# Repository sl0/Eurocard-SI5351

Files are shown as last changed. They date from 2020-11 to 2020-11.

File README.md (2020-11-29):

# Eurocard-SI5351

This repo will contain an arduino sketch and KiCad files for a pcb.
The pcb shall output stable 25 and 40 MHz sine, derived from a 10MHz
OCXO or external GPSDO 10MHz

## Licenses

The arduino sketch is licensed under the terms of GNU General Public
License.

    https://www.gnu.org/licenses/#GPL

Files in the kicad directory are 'Open Source' under the terms of the
definition for Open Source Hardware Association.

    http://www.oshwa.org/definition/

## Arduino Sketch

A first sketch I got from Wolfram DF7KB, after he made some experiments
to reduce phase noise. The genious trick was to rely on integer
operations only in the synthesizer. It was derived from the examples 
found in 
[etherkit libraries][].

## KiCad files

The schema of the board is easy:

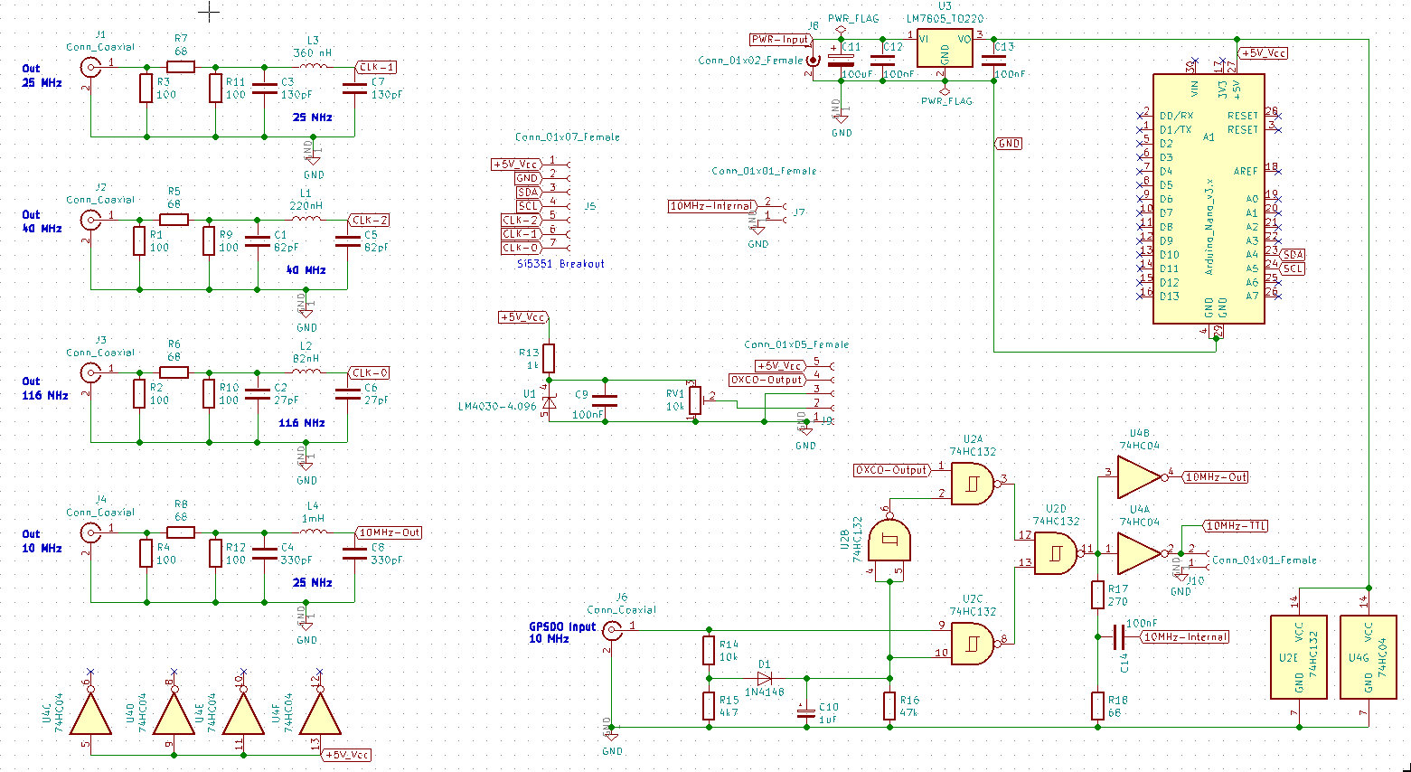
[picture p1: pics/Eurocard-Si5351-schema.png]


The routing of the pcb was done by hand:

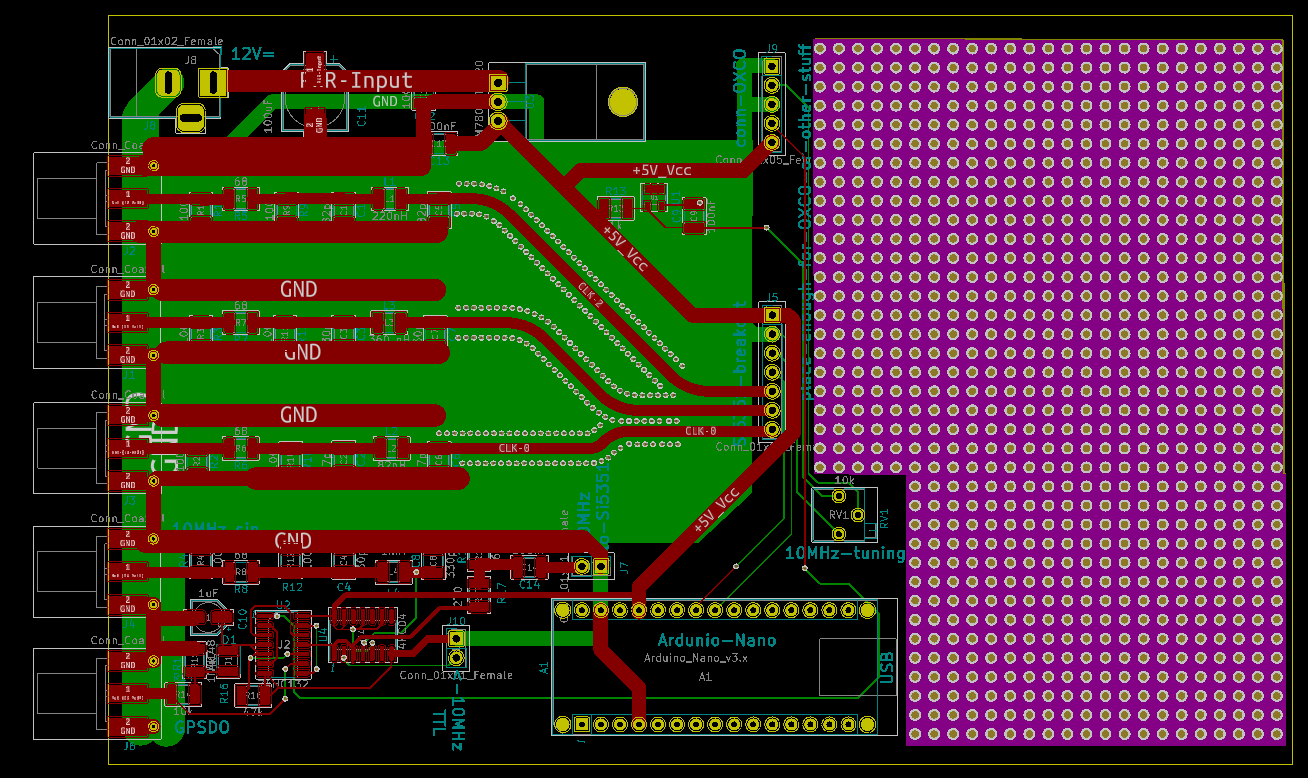
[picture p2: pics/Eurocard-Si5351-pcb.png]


    Have fun!

    sl0

[etherkit libraries]: https://github.com/etherkit/Si5351Arduino

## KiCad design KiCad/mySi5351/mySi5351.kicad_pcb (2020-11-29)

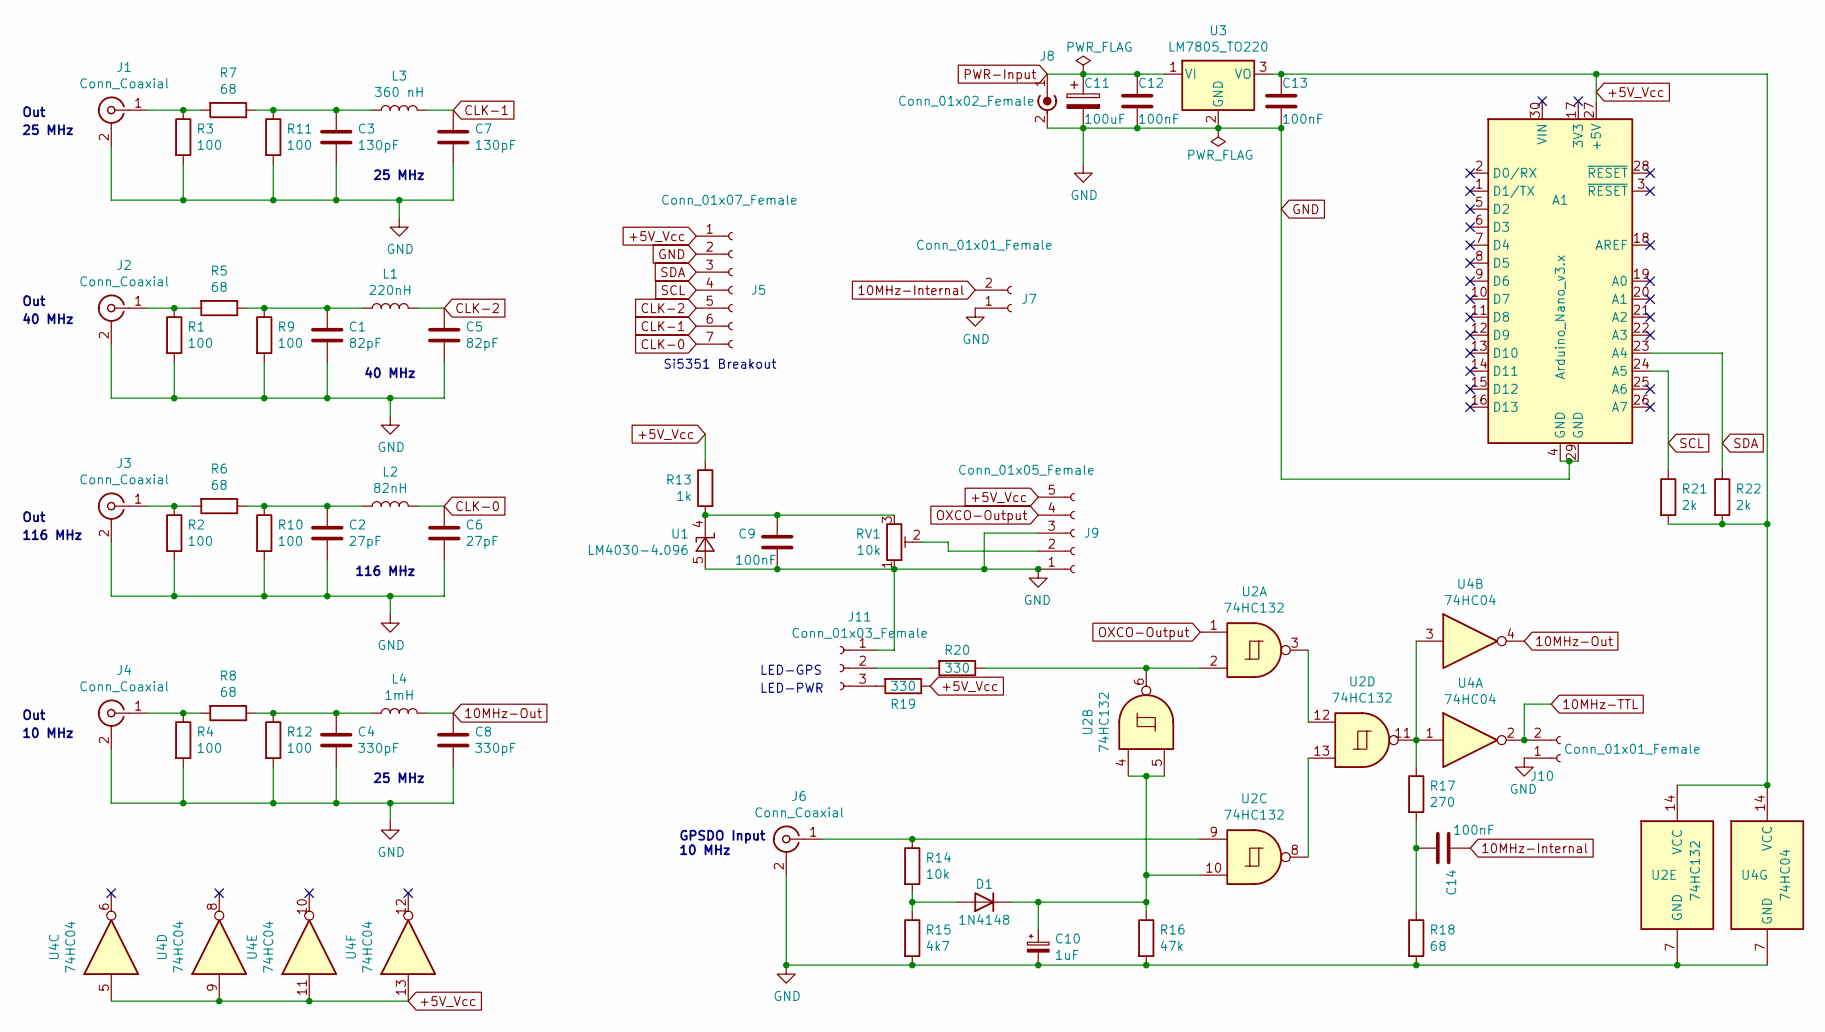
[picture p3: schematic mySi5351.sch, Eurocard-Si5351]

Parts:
A1: Arduino_Nano_v3.x; Arduino_Nano_WithMountingHoles
C1, C5: 82pF; C_1210_3225Metric_Pad1.33x2.70mm_HandSolder
C2, C6: 27pF; C_1210_3225Metric_Pad1.33x2.70mm_HandSolder
C3, C7: 130pF; C_1210_3225Metric_Pad1.33x2.70mm_HandSolder
C4, C8: 330pF; C_1210_3225Metric_Pad1.33x2.70mm_HandSolder
C9, C12, C13, C14: 100nF; C_1210_3225Metric_Pad1.33x2.70mm_HandSolder
C10: 1uF; CP_Elec_4x5.3
C11: 100uF; CP_Elec_8x10.5
D1: 1N4148; D_1210_3225Metric
J1, J2, J3, J4, J6: Conn_Coaxial; SMA_Molex_73251-1153_EdgeMount_Horizontal
J5: Conn_01x07_Female; PinHeader_1x07_P2.54mm_Vertical
J7, J10: Conn_01x01_Female; PinHeader_1x02_P2.54mm_Vertical
J8: Conn_01x02_Female; BarrelJack_Horizontal
J9: Conn_01x05_Female; PinHeader_1x05_P2.54mm_Vertical
J11: Conn_01x03_Female; PinHeader_1x03_P2.54mm_Vertical
L1: 220nH; L_1210_3225Metric_Pad1.42x2.65mm_HandSolder
L2: 82nH; L_1210_3225Metric_Pad1.42x2.65mm_HandSolder
L3: 360 nH; L_1210_3225Metric_Pad1.42x2.65mm_HandSolder
L4: 1mH; L_1210_3225Metric_Pad1.42x2.65mm_HandSolder
R1, R2, R3, R4, R9, R10, R11, R12: 100; R_1210_3225Metric_Pad1.30x2.65mm_HandSolder
R5, R6, R7, R8, R18: 68; R_1210_3225Metric_Pad1.30x2.65mm_HandSolder
R13: 1k; R_1210_3225Metric_Pad1.30x2.65mm_HandSolder
R14: 10k; R_1210_3225Metric_Pad1.30x2.65mm_HandSolder
R15: 4k7; R_1210_3225Metric_Pad1.30x2.65mm_HandSolder
R16: 47k; R_1210_3225Metric_Pad1.30x2.65mm_HandSolder
R17: 270; R_1210_3225Metric_Pad1.30x2.65mm_HandSolder
R19, R20: 330; R_1210_3225Metric_Pad1.30x2.65mm_HandSolder
R21, R22: 2k; R_1210_3225Metric_Pad1.30x2.65mm_HandSolder
RV1: 10k; Potentiometer_Bourns_3266P_Horizontal
U1: LM4030-4.096; SOT-23-5
U2: 74HC132; SO-14_3.9x8.65mm_P1.27mm
U3: LM7805_TO220; TO-220-3_Horizontal_TabDown
U4: 74HC04; SO-14_3.9x8.65mm_P1.27mm

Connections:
10MHz-Internal: C14.1, J7.2
10MHz-Out: C8.1, L4.2, U4.4
10MHz-TTL: J10.2, U4.2
+5V_Vcc: A1.27 (+5V), C13.1, J5.1, J9.5, R13.1, R19.1, R21.2, R22.2, U2.14 (VCC), U3.3 (VO), U4.5, U4.9, U4.11, U4.13, U4.14 (VCC)
CLK-0: C6.1, J5.7, L2.2
CLK-1: C7.1, J5.6, L3.2
CLK-2: C5.1, J5.5, L1.2
GND: A1.4 (GND), A1.29 (GND), C1.2, C2.2, C3.2, C4.2, C5.2, C6.2, C7.2, C8.2, C9.2, C10.2, C11.2, C12.2, C13.2, J1.2 (Ext), J2.2 (Ext), J3.2 (Ext), J4.2 (Ext), J5.2, J6.2 (Ext), J7.1, J8.2 (Ext), J9.1, J9.3, J10.1, J11.1, R1.2, R2.2, R3.2, R4.2, R9.2, R10.2, R11.2, R12.2, R15.2, R16.2, R18.2, RV1.1, U1.5 (A), U2.7 (GND), U3.2 (GND), U4.7 (GND)
unnamed: C1.1, L1.1, R5.1, R9.1
unnamed: C2.1, L2.1, R6.1, R10.1
unnamed: C3.1, L3.1, R7.1, R11.1
unnamed: C4.1, L4.1, R8.1, R12.1
unnamed: C9.1, R13.2, RV1.3, U1.4 (K)
unnamed: C10.1, D1.1 (K), R16.1, U2.4, U2.5, U2.10
unnamed: C14.2, R17.2, R18.1
unnamed: D1.2 (A), R14.2, R15.1
unnamed: J1.1 (In), R3.1, R7.2
unnamed: J2.1 (In), R1.1, R5.2
unnamed: J3.1 (In), R2.1, R6.2
unnamed: J4.1 (In), R4.1, R8.2
unnamed: J6.1 (In), R14.1, U2.9
unnamed: J9.2, RV1.2
unnamed: J11.2, R20.2
unnamed: J11.3, R19.2
unnamed: R17.1, U2.11, U4.1, U4.3
unnamed: R20.1, U2.2, U2.6
unnamed: U2.3, U2.12
unnamed: U2.8, U2.13
OXCO-Output: J9.4, U2.1
PWR-Input: C11.1, C12.1, J8.1 (In), U3.1 (VI)
SCL: A1.24 (A5), J5.4, R21.1
SDA: A1.23 (A4), J5.3, R22.1

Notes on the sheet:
Si5351 Breakout
GPSDO Input 10 MHz
25 MHz
40 MHz
116 MHz
10 MHz
Out
LED-GPS
LED-PWR

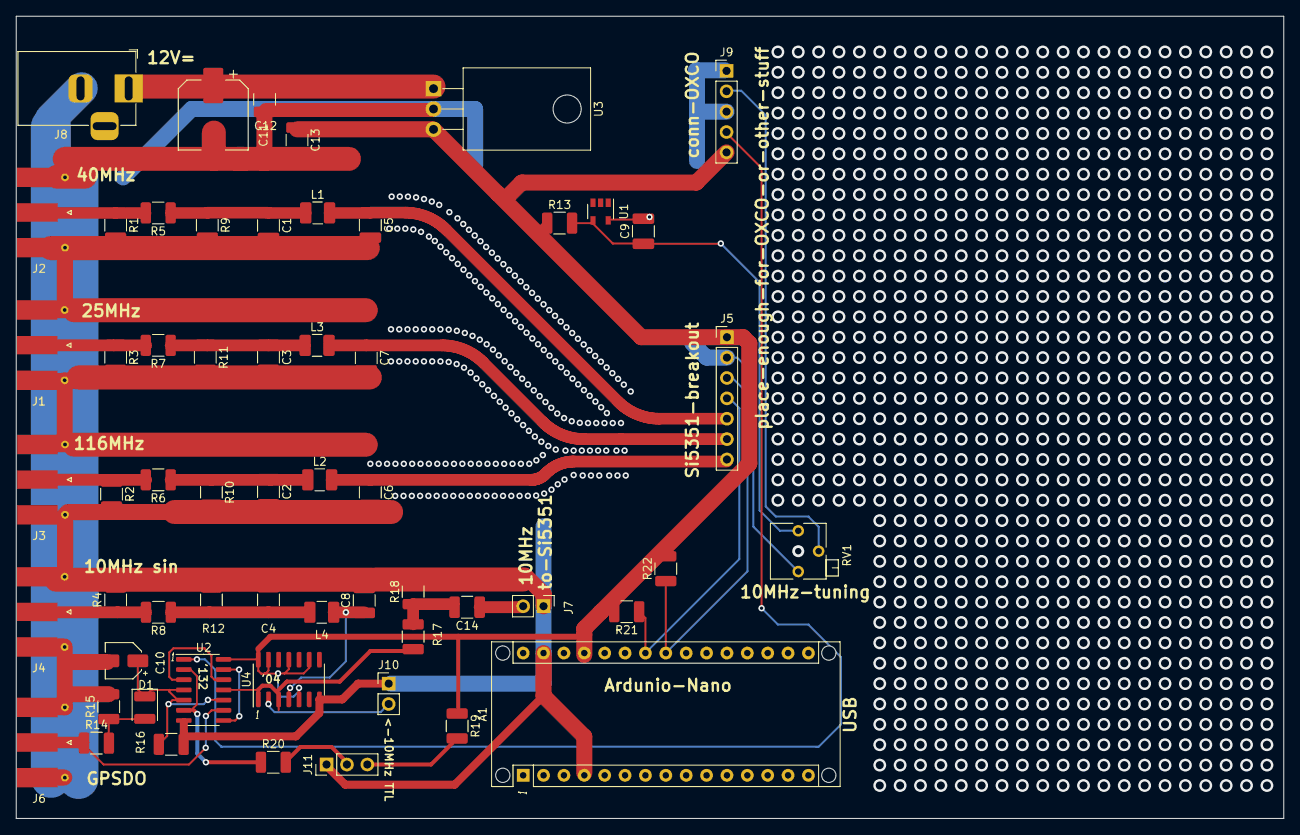
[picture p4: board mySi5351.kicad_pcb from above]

Board: 2 copper layers, 158.0 x 100.0 mm, 58 parts (0 on the bottom side), 32 nets.

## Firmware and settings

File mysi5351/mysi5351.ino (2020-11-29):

/*
 * mysi5351.ino - Simply configure Si5351 synthesizer for 25 + 40 MHz
 *
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
 * This arduino sketch configures an i2c connected Si5351 Synthesizer chip
 * to have stable and exact base frequencies:
 *    25 MHz for a LNB directed to QO-100.
 *    40 MHz for an Adalm-Pluto to replace its internal XO
 *
 * These are prerequisites to have reliable and exact frequency numbers
 * within the Pluto and connected Software.
 *
 * For less distrubing noise the arduino is going to sleep mode after
 + having configured the synthesizers.
 *
 * The sketch is independent of the Si5351 onboard XO. To get exact results,
 * this needs to be replaced by a separate OXCO or a GPSDO. Nevertheless
 * the sketch works as well to produce less reliable signals with the
 * soldered oscillater on the breakout board.
 *
 * Si5351 Synthesizers are available from etherkit.com:
 *          https://www.etherkit.com/rf-modules/si5351a-breakout-board.html
 *   or from Adafruit Industries:
 *          https://learn.adafruit.com/adafruit-si5351-clock-generator-breakout
 *
 *
 * Thanks to Jason Milldrum <milldrum@gmail.com> for his library:
 *          https://github.com/etherkit/Si5351Arduino
 *
 * Thanks to Wolf DF7KB and Klaus DC6CM for their helpful hints.
 *
 * Have fun!
 * 73 de Johannes, DO1SLO
 */

#define DEBUG

#include <avr/sleep.h>
#include "si5351.h"
#include "Wire.h"

#define Led_Pin 13
#define Led_On          {digitalWrite(Led_Pin, HIGH);}
#define Led_Off         {digitalWrite(Led_Pin, LOW);}

#define DFLT_FREQ     25000000      // use onboard xtal
#define XTAL_FREQ     10000000      // external oscillator
//                                     needs desoldered xtal and wire

// decide here if you have desoldered xtal
#define BASIC_FREQ    XTAL_FREQ

Si5351 si5351;

/*  enter_sleep() was taken from
    http://www.netzmafia.de/skripten/hardware/Arduino/Sleep/index.html
    (c) by Hochschule Muenchen, FK04, Prof. Jürgen Plate
*/

#define SLEEP_MODE SLEEP_MODE_PWR_DOWN

void enter_sleep(void)
{
    set_sleep_mode(SLEEP_MODE);
    sleep_enable();
    sleep_mode();
    /** Das Programm läuft ab hier nach dem Aufwachen weiter. **/
    /** Es wird immer zuerst der Schlafmodus disabled.        **/
    sleep_disable();
}


void setup()
{
    bool i2c_found;

    pinMode(Led_Pin, OUTPUT);
    Led_On;

#ifdef DEBUG
    // Start serial and initialize the Si5351
    Serial.begin(115200);
    Serial.println("Arduino init starts");
#endif
    i2c_found = si5351.init(SI5351_CRYSTAL_LOAD_8PF, BASIC_FREQ, 0);
#ifdef DEBUG
    if(!i2c_found) {
      Serial.println("Device not found on I2C bus!");
    } else {
      Serial.println("Si5351 device found on I2C bus!");
      Serial.println("Initializing the synthesizer ...");
    }
#endif

    // CLK0 is not used now
    si5351.output_enable(SI5351_CLK0, 0);

    // CLK1 and CLK2 are used
    si5351.output_enable(SI5351_CLK1, 1);
    si5351.output_enable(SI5351_CLK2, 1);

    si5351.drive_strength(SI5351_CLK1, SI5351_DRIVE_4MA);
    si5351.drive_strength(SI5351_CLK2, SI5351_DRIVE_4MA);

    // Set CLK1 to output 25 MHz with PLL A ( x 32)
    si5351.set_ms_source(SI5351_CLK1, SI5351_PLLA);
    si5351.set_freq_manual(2500000000ULL, 80000000000ULL, SI5351_CLK1);

    // Set CLK2 to output 40 MHz with PLL B (x 16)
    si5351.set_ms_source(SI5351_CLK2, SI5351_PLLB);
    si5351.set_freq_manual(4000000000ULL, 64000000000ULL, SI5351_CLK2);

    // Query a status update and wait a bit to let the Si5351 populate the
    // status flags correctly.
    si5351.update_status();
    delay(1500);
#ifdef DEBUG
      Serial.println("Init ready, starting normal operation ...");
#endif
}

void loop()
{
    // Read the Status Register and print it once
    si5351.update_status();
#ifdef DEBUG
    Serial.println("Synthesizer status:");
    Serial.print("SYS_INIT: ");
    Serial.print(si5351.dev_status.SYS_INIT);
    Serial.print("  LOL_A: ");
    Serial.print(si5351.dev_status.LOL_A);
    Serial.print("  LOL_B: ");
    Serial.print(si5351.dev_status.LOL_B);
    Serial.print("  LOS: ");
    Serial.print(si5351.dev_status.LOS);
    Serial.print("  REVID: ");
    Serial.println(si5351.dev_status.REVID);
#endif
    delay(1500);
#ifdef DEBUG
    Serial.println("Entering sleep mode, operation continues ...");
    delay(20);
#endif
    Led_Off;
    // power down to sleep mode, don't do anything more!
    enter_sleep();
    // usually the following will never run
    delay(10000);
}
// EoF

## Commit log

2020-11-29 Adds first sketch in arduino-ide compatible directory
2020-11-29 Adds arduino-mk makefile
    updates .gitignore about products
2020-11-29 Adds schema and empty eurocard pcb
    [mySi5351.kicad_pcb, mySi5351.sch]
2020-11-29 Adds manual routes to pcb
    via grid and rounded traces looking well now
    [mySi5351.sch]
2020-11-29 Review, plotted files for first useable pcb
    The plots are products and send to factory, not included in repo
    [mySi5351.kicad_pcb, mySi5351.sch]
2020-12-04 Fixed a bug in schema, 100 instead of 10k Ohms
    [mySi5351.sch]

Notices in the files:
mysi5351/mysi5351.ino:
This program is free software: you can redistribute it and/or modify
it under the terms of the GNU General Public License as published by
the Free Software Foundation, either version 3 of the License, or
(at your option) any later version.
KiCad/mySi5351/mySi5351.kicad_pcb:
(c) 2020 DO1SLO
